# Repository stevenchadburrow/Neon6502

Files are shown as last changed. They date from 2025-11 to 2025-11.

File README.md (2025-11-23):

# Neon6502

<b>Compact 6502 build using 74' logic chips.</b>

The idea with this project is to make a cheap 4" x 4" PCB that can fit most of the functionality of my original <a href="https://github.com/stevenchadburrow/AcolyteComputer">Acolyte Computer</a>.  The purpose is to play games such as Tetris and Space Invaders clones that I will program in 6502 assembly.  I also made a simulator program is to help speed up development time and lessen the amount of Flash ROM burns.<br>

I'm doing this in order to wait for the <a href="https://www.microchip.com/en-us/product/PIC32CZ8110CA80144">PIC32CZ8110CA80144</a> microcontroller to come out in the LQFP-144 package (promised Q4 of 2025!).  Once that is out, I will get back to projects similar to my <a href="https://github.com/stevenchadburrow/AcolyteHandheld">Acolyte Handheld<a>.<br>

<b>Specs:</b><br>
- W65C02 running at 3.14 MHz<br>
- 32 KB of RAM (30 KB of which is Video RAM)<br>
- 32 KB of ROM (4x switchable banks)<br>
- 8x Built-in Buttons<br>
- VGA Output of 320x240 in 4-colors<br>
- Uses only 74' logic chips and the Flash ROM to generate the video signal!<br>
- USB-B to power device<br>
- No VIA, no UART, no keyboard, no audio, no external memory<br>

<b>Memory Map:</b><br>
- $0000 - $07FF = RAM<br>
- $0800 - $7FFF = Video RAM<br>
- $8000 - $FFFF = ROM<br>

<b>History:</b><br>
As this is a revisiting of previous projects and skills, I feel the need to try to catalog my progress up to this point.  Below is a timeline of projects completed with a few details.<br>
- Aug 2021: After the quarantine, I went back to work at the school physically.  I never went upstairs into my office but stayed in my classroom with a Linux computer to occupy my time.  I started researching how to make a water-based calculator, but found electricity to be far better.  I researched about 74' logic chips and eventually reached out to Garth who redirected me to the 6502.org Forum <a href="http://forum.6502.org/">here</a>.
- Oct 2021: This marks the very beginning of the journey, my first 6502 build, called "V1" by Bill (plasmo).  Made on perf-board, each wire hand-soldered.  I had crossed A4 and A11 on the RAM, Bill found this and fixed it for me.  It had only a couple of buttons and a 16x2 LCD.
- Nov 2021: I made a duplicate of V1 on a PCB, which I called "V2".  No bodges were required, though it wasn't very useful.  Far later I would use this as the basis for a project where Elizabeth soldered her own computer together.
- Jan 2022: I made V3 and even a V4, adding features such as PS/2 keyboard and ROM banks.  I tried to add VGA video using 74' logic chips for all sync calculations, but they were all failures.
- Mar 2022: In order to create a VGA video signal, I created my "Half a Pi" board, using a dedicated Flash ROM for video signals.  It was able to output White, Red, Cyan, and Black.  I was able to showcase it at the upcoming Math Appreciation Day 2022 <a href="http://forum.6502.org/viewtopic.php?f=1&t=7092">here</a>.
- Jul 2022: By now I had tried to replicate the "Half a Pi" with more complexity, and yet I continued to have failures.  At some point I had started calling them "Acolyte", though apparently the first versions were not operational.  The main goal was to combine both the sync signals and the program code onto a single Flash ROM.  Some were successes, even if they were complex, found <a href="http://forum.6502.org/viewtopic.php?f=4&t=7154">here</a>.
- Nov 2022: At this point I was still making mistakes and a lot of my PCBs would not work.  A revelation came to be at some point here that I could simply bodge wires to fix problems, which helped a lot.  You can find a lot of the discussion <a href="http://forum.6502.org/viewtopic.php?f=4&t=7407">here</a>.
- Jan 2023: The final culmination of the original Acolyte computers comes together <a href="https://github.com/stevenchadburrow/AcolyteComputer">here</a>.  It was named "Last Acolyte II".  It has so many bodge wires, mostly for experimenting and adding a VIA into the expansion area.  The back of that board looks like spagetti with all of the bodges!  It had Tetris, Space Invaders, BASIC, and a Monitor program.
- Apr 2023: I started designing the "Serial VGA" projects <a href="https://github.com/stevenchadburrow/SerialVGA">here</a>, which could be connected to any random 6502 computer.  After some revisions they started to work, but were not very efficient, being too slow.  I also played around with the Arduino, and created a CPLD-based shield <a href="https://github.com/stevenchadburrow/ArduinoShield">here</a>.
- Sep 2023: By now I had been working with CPLDs and learning Verilog, and created what I called "New Acolyte" <a href="https://github.com/stevenchadburrow/NewAcolyte">here</a>, which ran twice as fast and relied on the CPLD for video generation with 16 colors.  I connected a Sega Genesis controller to it, and was able to create many fun games for it, including Tetris, Space Invaders, Missile Command, Rogue, and Galaga clones.
- Dec 2023: After other failed revisions, it was time to go bigger and better, and so I developed my 'masterpiece', the "Acolyte816" <a href="https://github.com/stevenchadburrow/Acolyte816">here</a>.  It used a 65816 processor, CPLD for video generation, and a PIC16 micrcontroller for bootloading.  It did work, but was so complex that it was very hard to develop for.  Because of that, not much time was spent on it.
- Feb 2024: Enticed by the PIC16 which Garth had introduced to me, I started work on a PIC18 microcontroller based computer called "Acolyte Hand PIC'd", found <a href="https://github.com/stevenchadburrow/AcolyteHandPICd">here</a>.  It was a separation from the 6502 based computers, finally breaking away and being able to use C programming.  It still using a CPLD and external RAM for video generation.  I was able to get Tetris to run on it.  I would try another PIC18 project later that failed to work because I made it too complex.
- May 2024: I created a PIC24 microcontroller based computer called "Acolyte Hand PIC'd 24" <a href="https://github.com/stevenchadburrow/AcolyteHandPICd24">here</a>.  I was final able to break away from using the CPLD and external RAM for video generation, still yielding 16 colors.  Small additions to test USB host and device capabilities were added.  Then during Summer 2024 I created a two-player Pokemon clone for this computer, pushing the PIC24 to the very limit.
- Oct 2024: I upgraded to the PIC32 microcontroller, creating a computer called the "Acolyte Hand PIC'd 32" with absolutely stunning results <a href="https://github.com/stevenchadburrow/AcolyteHandPICd32">here</a>.  I started running it at 200 MHz, displaying 256 colors.  I bodged in better audio capabilities using an R2R DAC and was able to play video/audio streams.
- Dec 2024: After trying to port an NES emulator to the PIC32 board, and failing to reach the needed speed, I found the Peanut-GB Emulator by Mahyar <a href="https://github.com/deltabeard/Peanut-GB">here</a>.  It ran Gameboy games at full speed.  I quickly made a second revision of the PIC32 board with 64K color capability and 2x 8-bit R2R DACs.
- Jan 2025: Wanting to create a handheld device of some kind, I created "Mon Catcher" using a PIC24 and a small LCD.  It was going to be a dedicated device that would act similar to Pokemon GO, using sensors to detect movement.  It worked, but the sensors were not great and I got bored of it quickly. ( No links provided. )
- Feb 2025: I started work on what would later be called "PICnes" <a href="https://github.com/stevenchadburrow/PICnes">here</a>.  By April 2025 it would have all of the popular NES mappers including MMC3.
- Jun 2025: My dream forever has been to have a 'switchable' platform, and so I finally created the "Acolyte Handheld" <a href="https://github.com/stevenchadburrow/AcolyteHandheld">here</a>.  Capable of switching between VGA and LCD outputs, and being overclocked to 300 MHz, it was able to run nearly all NES games at full speed.  Along with Peanut-GB, I added TotalSMS <a href="https://github.com/ITotalJustice/TotalSMS">here</a>, for Sega Master System and Game Gear games.  Over Summer 2025 it was finalized.
- Aug 2025: In an attempt to shrink the Acolyte Handheld down, I created what I called the "Second Handheld", which would be my 'masterpiece' with the PIC32.  Unfortunately, I was not able to overclock it to 300 MHz, and many of the complex features such as external Flash ROM I had added were not working.  It ultimately ended a failure, however beautiful it was.  It seems that my 'masterpieces' always end in failure? ( No links provided. )
- Sep 2025: Seeking to make the next project better than the PIC32, I started the "RPi02W-Emulators" project <a href="https://github.com/stevenchadburrow/RPi02W-Emulators">here</a>.  Using a Raspberry Pi Zero 2W, I was able to make it 'switchable' between and LCD screen and HDMI output.  Programming in Linux was very enjoyable, though ultimately this project also proved to be a failure.  It ran NES and GB games easily enough, but Gameboy Advance games were still too slow.  The screen would have a tearing effect and the audio was scratchy, mainly because I decided to user /dev/fb0 and /dev/dsp for all of my video and audio needs.  The Linux overhead just didn't make it work as well as I had wanted.  It does run Freedoom, but only on HDMI.
- Nov 2025: And here we are, creating "Neon6502".  There is my journey.

<b>Links:</b><br>
<a href="https://www.youtube.com/shorts/nDpJQxdZJzY">Youtube Short playing Tetra</a><br>

<b>Pictures:</b><br>
Pictures of the PCB design, some footprints too small. Gerber files included.<br>
<br>
Testing out the image converter, assembly code, and simulator.<br>
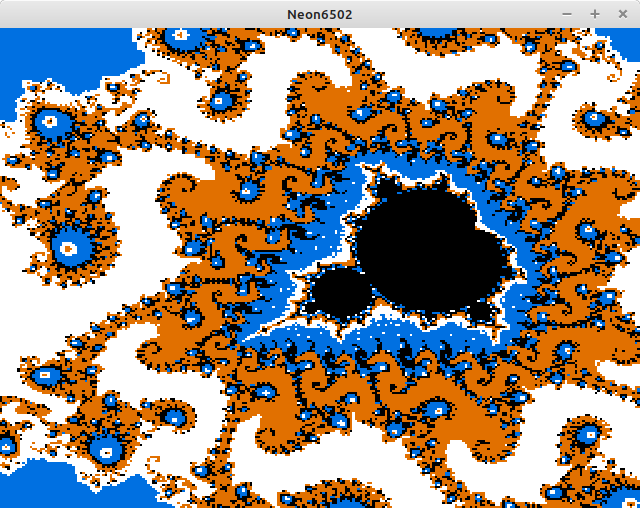
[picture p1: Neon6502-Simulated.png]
<br>
Soldered PCB with all components.  Only one bodge wire!<br>
<br>
Actual program on VGA monitor.<br>
<br>
Tetra is always the first game.<br>
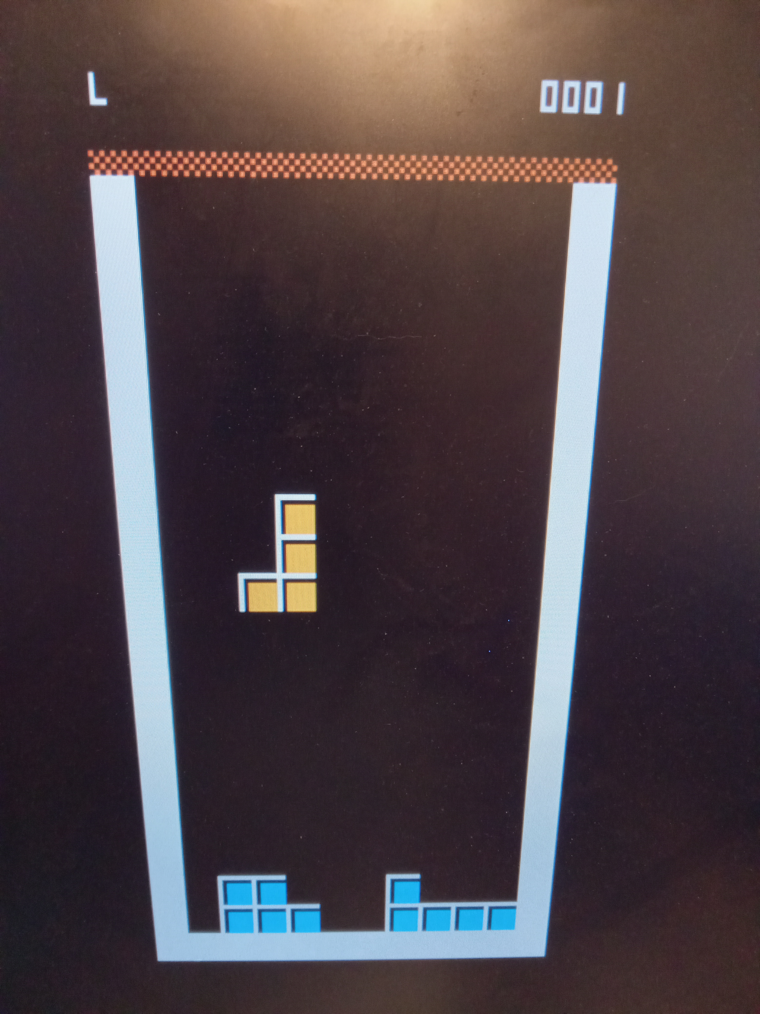
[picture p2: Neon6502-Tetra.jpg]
<br>
Enclosure uses same color palette.<br>
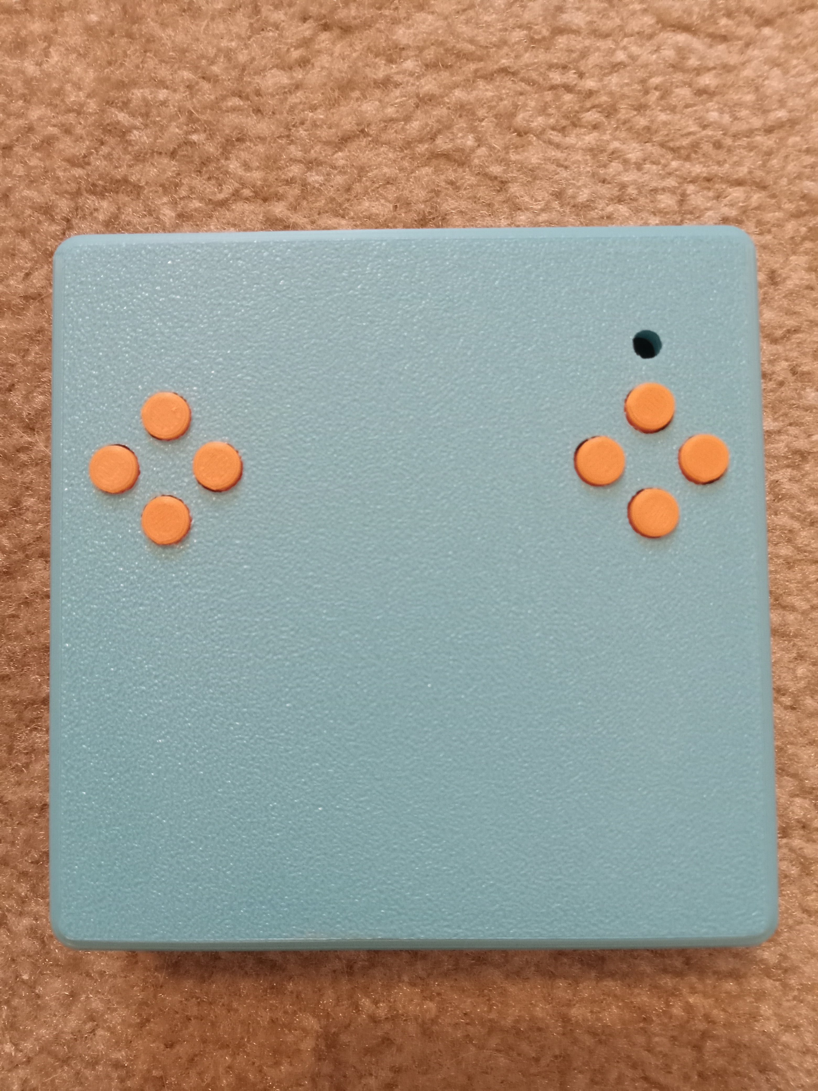
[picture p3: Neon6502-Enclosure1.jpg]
<br>
Ports fit flush with enclosure.<br>
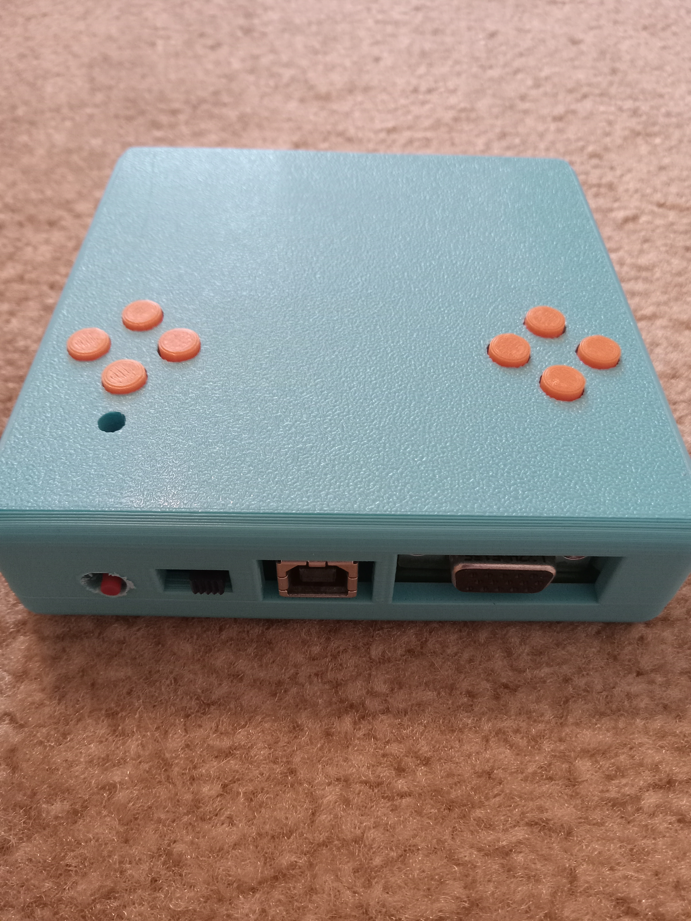
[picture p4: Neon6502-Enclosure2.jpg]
<br>

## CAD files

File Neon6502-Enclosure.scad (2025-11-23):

// Neon6502

module radiusedblock(xlen,ylen,zlen,radius) {
	hull() {
		translate([radius,radius,radius]) sphere(r=radius);
		translate([xlen + radius , radius , radius]) sphere(r=radius);
		translate([radius , ylen + radius , radius]) sphere(r=radius);    
		translate([xlen + radius , ylen + radius , radius]) sphere(r=radius);
		translate([radius , radius , zlen + radius]) sphere(r=radius);
		translate([xlen + radius , radius , zlen + radius]) sphere(r=radius);
		translate([radius,ylen + radius,zlen + radius]) sphere(r=radius);
		translate([xlen + radius,ylen + radius,zlen + radius]) sphere(r=radius);
	}
}

$fn = 20; // higher detail to curves


scale([1,-1,1])
{
	difference()
	{
		// outside
		translate([-5,-5,-5])
		{
			radiusedblock(100,100,20,5);
		}
		
		// inside
		translate([-1,-1,0])
		{
			cube([102,102,20]);
		}
			
		// vga
		translate([9,-10,5])
		{
			cube([33,20,14]);
		}
			
		// usb
		translate([45,-10,5])
		{
			cube([17.5,20,12]);
		}
		
		// switch
		translate([67,-10,7])
		{
			cube([11,20,7]);
		}
		
		// reset
		translate([85.75,-10,4])
		{
			rotate([-90,0,0])
			{
				cylinder(20,2.5,2.5);
			}
		}
		
		// led
		translate([86.25,15.0,10])
		{
			cylinder(20,2.5,2.5);
		}
		
		// buttons
		translate([14.25,24.75,10])
		{
			cylinder(20,4,4);
		}
		translate([14.25,40.25,10])
		{
			cylinder(20,4,4);
		}
		translate([6.5,32.5,10])
		{
			cylinder(20,4,4);
		}
		translate([22.0,32.5,10])
		{
			cylinder(20,4,4);
		}
		
		translate([86.25,24.75,10])
		{
			cylinder(20,4,4);
		}
		translate([86.25,40.25,10])
		{
			cylinder(20,4,4);
		}
		translate([78.5,32.5,10])
		{
			cylinder(20,4,4);
		}
		translate([94.0,32.5,10])
		{
			cylinder(20,4,4);
		}
		
		// screw holes
		translate([4.75,4.75,5])
		{
			rotate([180,0,0])
			{
				cylinder(20,2.5,2.5);
			}
		}
		translate([95.25,4.75,5])
		{
			rotate([180,0,0])
			{
				cylinder(20,2.5,2.5);
			}
		}
		translate([4.75,95.25,5])
		{
			rotate([180,0,0])
			{
				cylinder(20,2.5,2.5);
			}
		}
		translate([95.25,95.25,5])
		{
			rotate([180,0,0])
			{
				cylinder(20,2.5,2.5);
			}
		}
		
		// comment out for top only
		translate([-10,-10,-10])
		{
			//cube([120,120,10+5]);
		}
		
		// comment out for bottom only
		translate([-10,-10,5])
		{
			//cube([120,120,30]);
		}
	}
	
	difference()
	{
		union()
		{
			// screw supports
			translate([4.75,4.75,0])
			{
				difference()
				{
					cylinder(20,4.5,4.5);
					cylinder(20,1.0,1.0);
				}
			}
			translate([95.25,4.75,0])
			{
				difference()
				{
					cylinder(20,4.5,4.5);
					cylinder(20,1.0,1.0);
				}
			}
			translate([4.75,95.25,0])
			{
				difference()
				{
					cylinder(20,4.5,4.5);
					cylinder(20,1.0,1.0);
				}
			}
			translate([95.25,95.25,0])
			{
				difference()
				{
					cylinder(20,4.5,4.5);
					cylinder(20,1.0,1.0);
				}
			}
			
			// support supports
			translate([1,1,0])
			{
				cylinder(20,3,3);
			}
			translate([99,1,0])
			{
				cylinder(20,3,3);
			}
			translate([1,99,0])
			{
				cylinder(20,3,3);
			}
			translate([99,99,0])
			{
				cylinder(20,3,3);
			}
			
			// button supports
			translate([14.25,24.75,15])
			{
				difference()
				{
					cylinder(5,6,6);
					cylinder(5,4,4);
				}
			}
			translate([14.25,40.25,15])
			{
				difference()
				{
					cylinder(5,6,6);
					cylinder(5,4,4);
				}
			}
			translate([6.5,32.5,15])
			{
				difference()
				{
					cylinder(5,6,6);
					cylinder(5,4,4);
				}
			}
			translate([22.0,32.5,15])
			{
				difference()
				{
					cylinder(5,6,6);
					cylinder(5,4,4);
				}
			}
		
			translate([86.25,24.75,15])
			{
				difference()
				{
					cylinder(5,6,6);
					cylinder(5,4,4);
				}
			}
			translate([86.25,40.25,15])
			{
				difference()
				{
					cylinder(5,6,6);
					cylinder(5,4,4);
				}
			}
			translate([78.5,32.5,15])
			{
				difference()
				{
					cylinder(5,6,6);
					cylinder(5,4,4);
				}
			}
			translate([94.0,32.5,15])
			{
				difference()
				{
					cylinder(5,6,6);
					cylinder(5,4,4);
				}
			}
		}
		
		// pcb
		translate([-10,-10,5-1.6])
		{
			cube([120,120,1.6]);
		}
		
		// comment out for top only
		translate([-10,-10,-10])
		{
			//cube([120,120,10+5]);
		}
		
		// comment out for bottom only
		translate([-10,-10,5])
		{
			//cube([120,120,30]);
		}
	}
}

module button()
{
	difference()
	{
		union()
		{
			cylinder(15, 3.5, 3.5);
			cylinder(2, 5, 5);
			intersection()
			{
				sphere(17);
				cylinder(100, 3.5, 3.5);
			}
		}
		translate([-1.5, -1.5, 0])
		{
			cube([3.0, 3.0, 3.0]);
		}
	}
}


scale([1,-1,1])
{
	translate([14.25,24.75,10])
	{
		button();
	}
	translate([14.25,40.25,10])
	{
		button();
	}
	translate([6.5,32.5,10])
	{
		button();
	}
	translate([22.0,32.5,10])
	{
		button();
	}
	
	translate([86.25,24.75,10])
	{
		button();
	}
	translate([86.25,40.25,10])
	{
		button();
	}
	translate([78.5,32.5,10])
	{
		button();
	}
	translate([94.0,32.5,10])
	{
		button();
	}
}

//button();

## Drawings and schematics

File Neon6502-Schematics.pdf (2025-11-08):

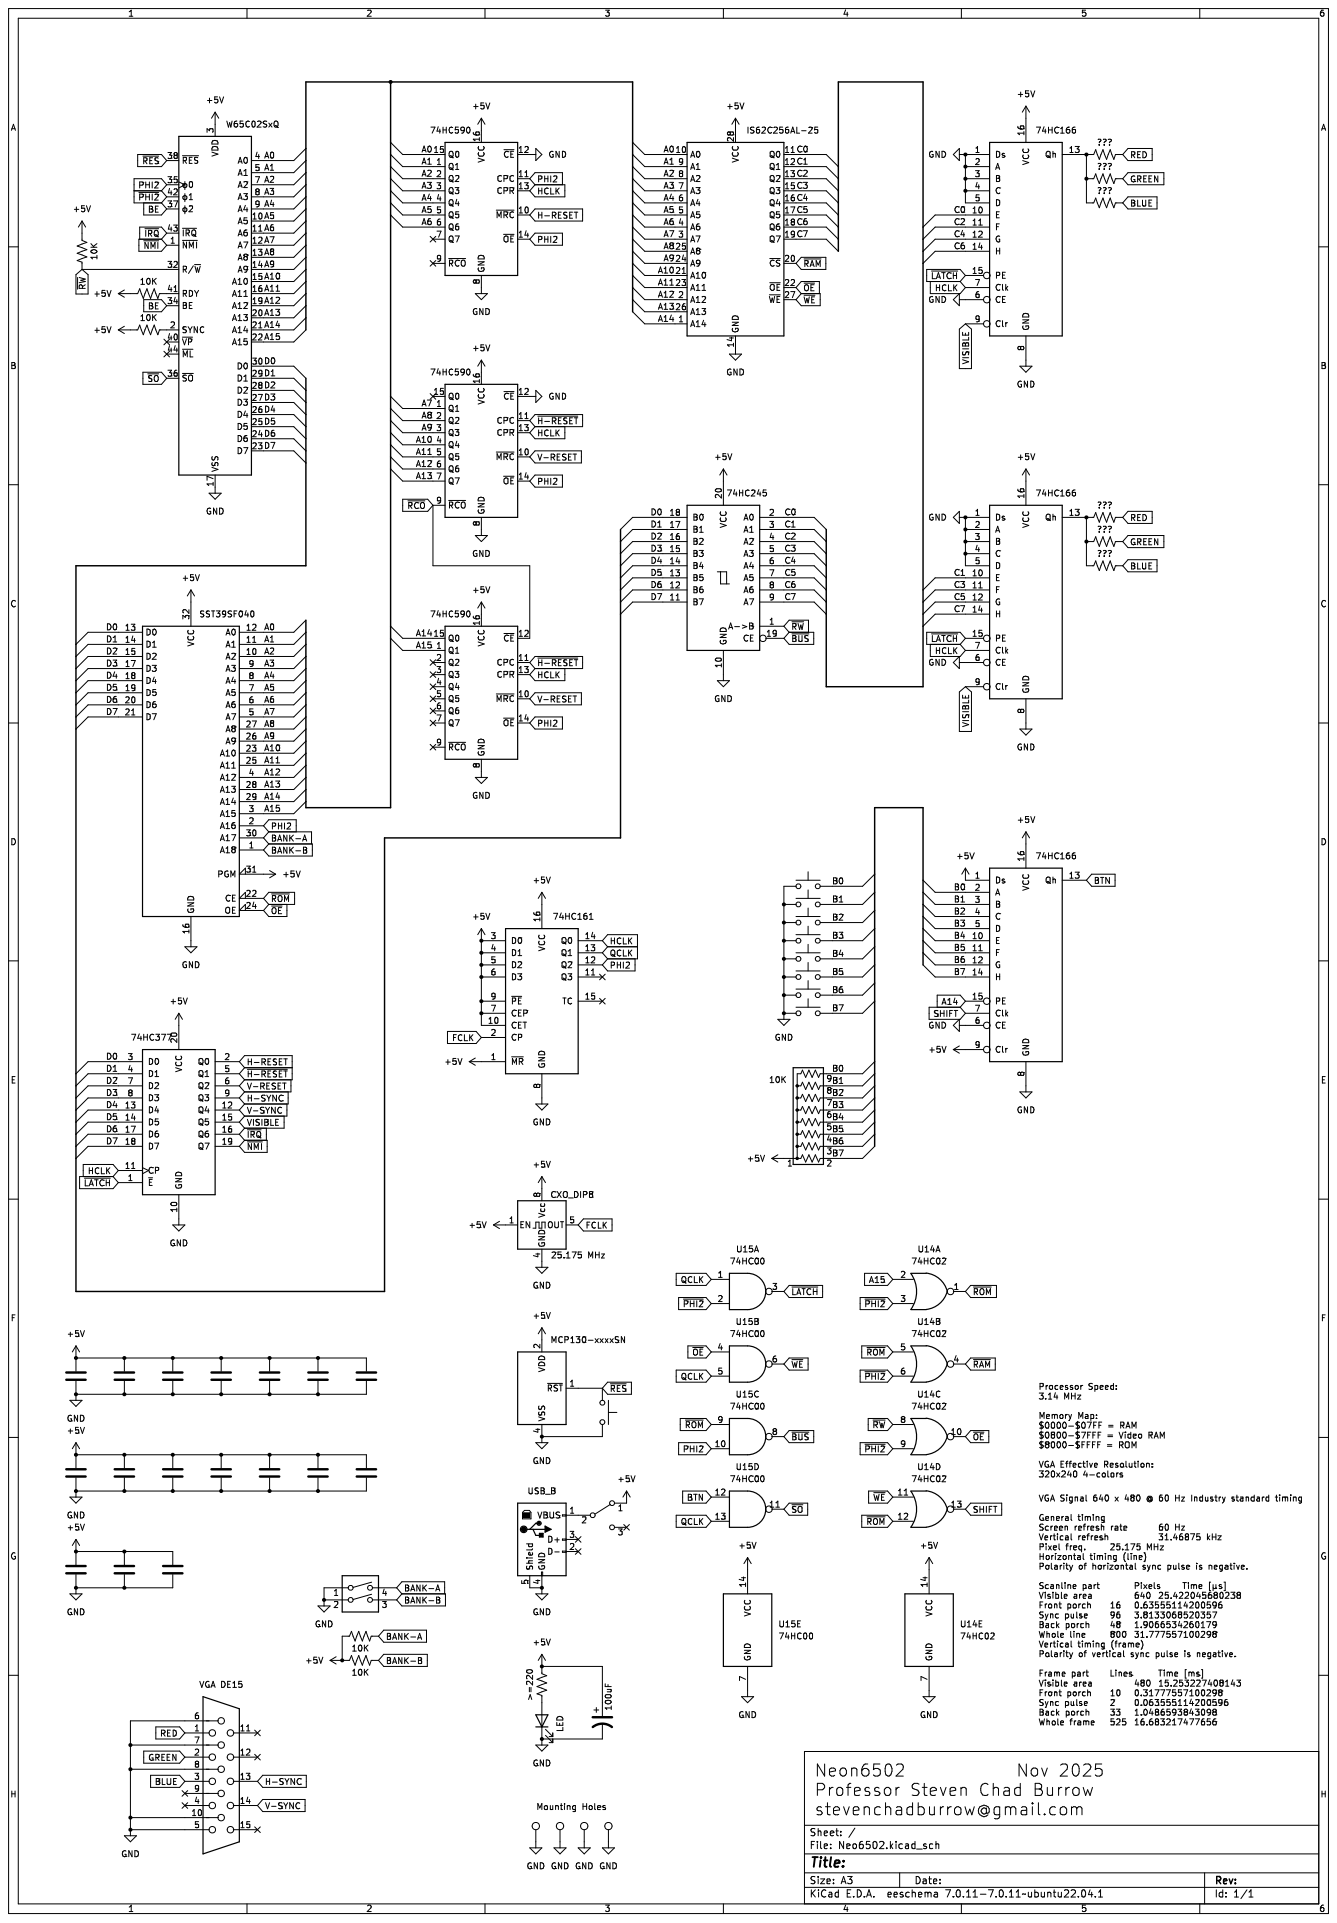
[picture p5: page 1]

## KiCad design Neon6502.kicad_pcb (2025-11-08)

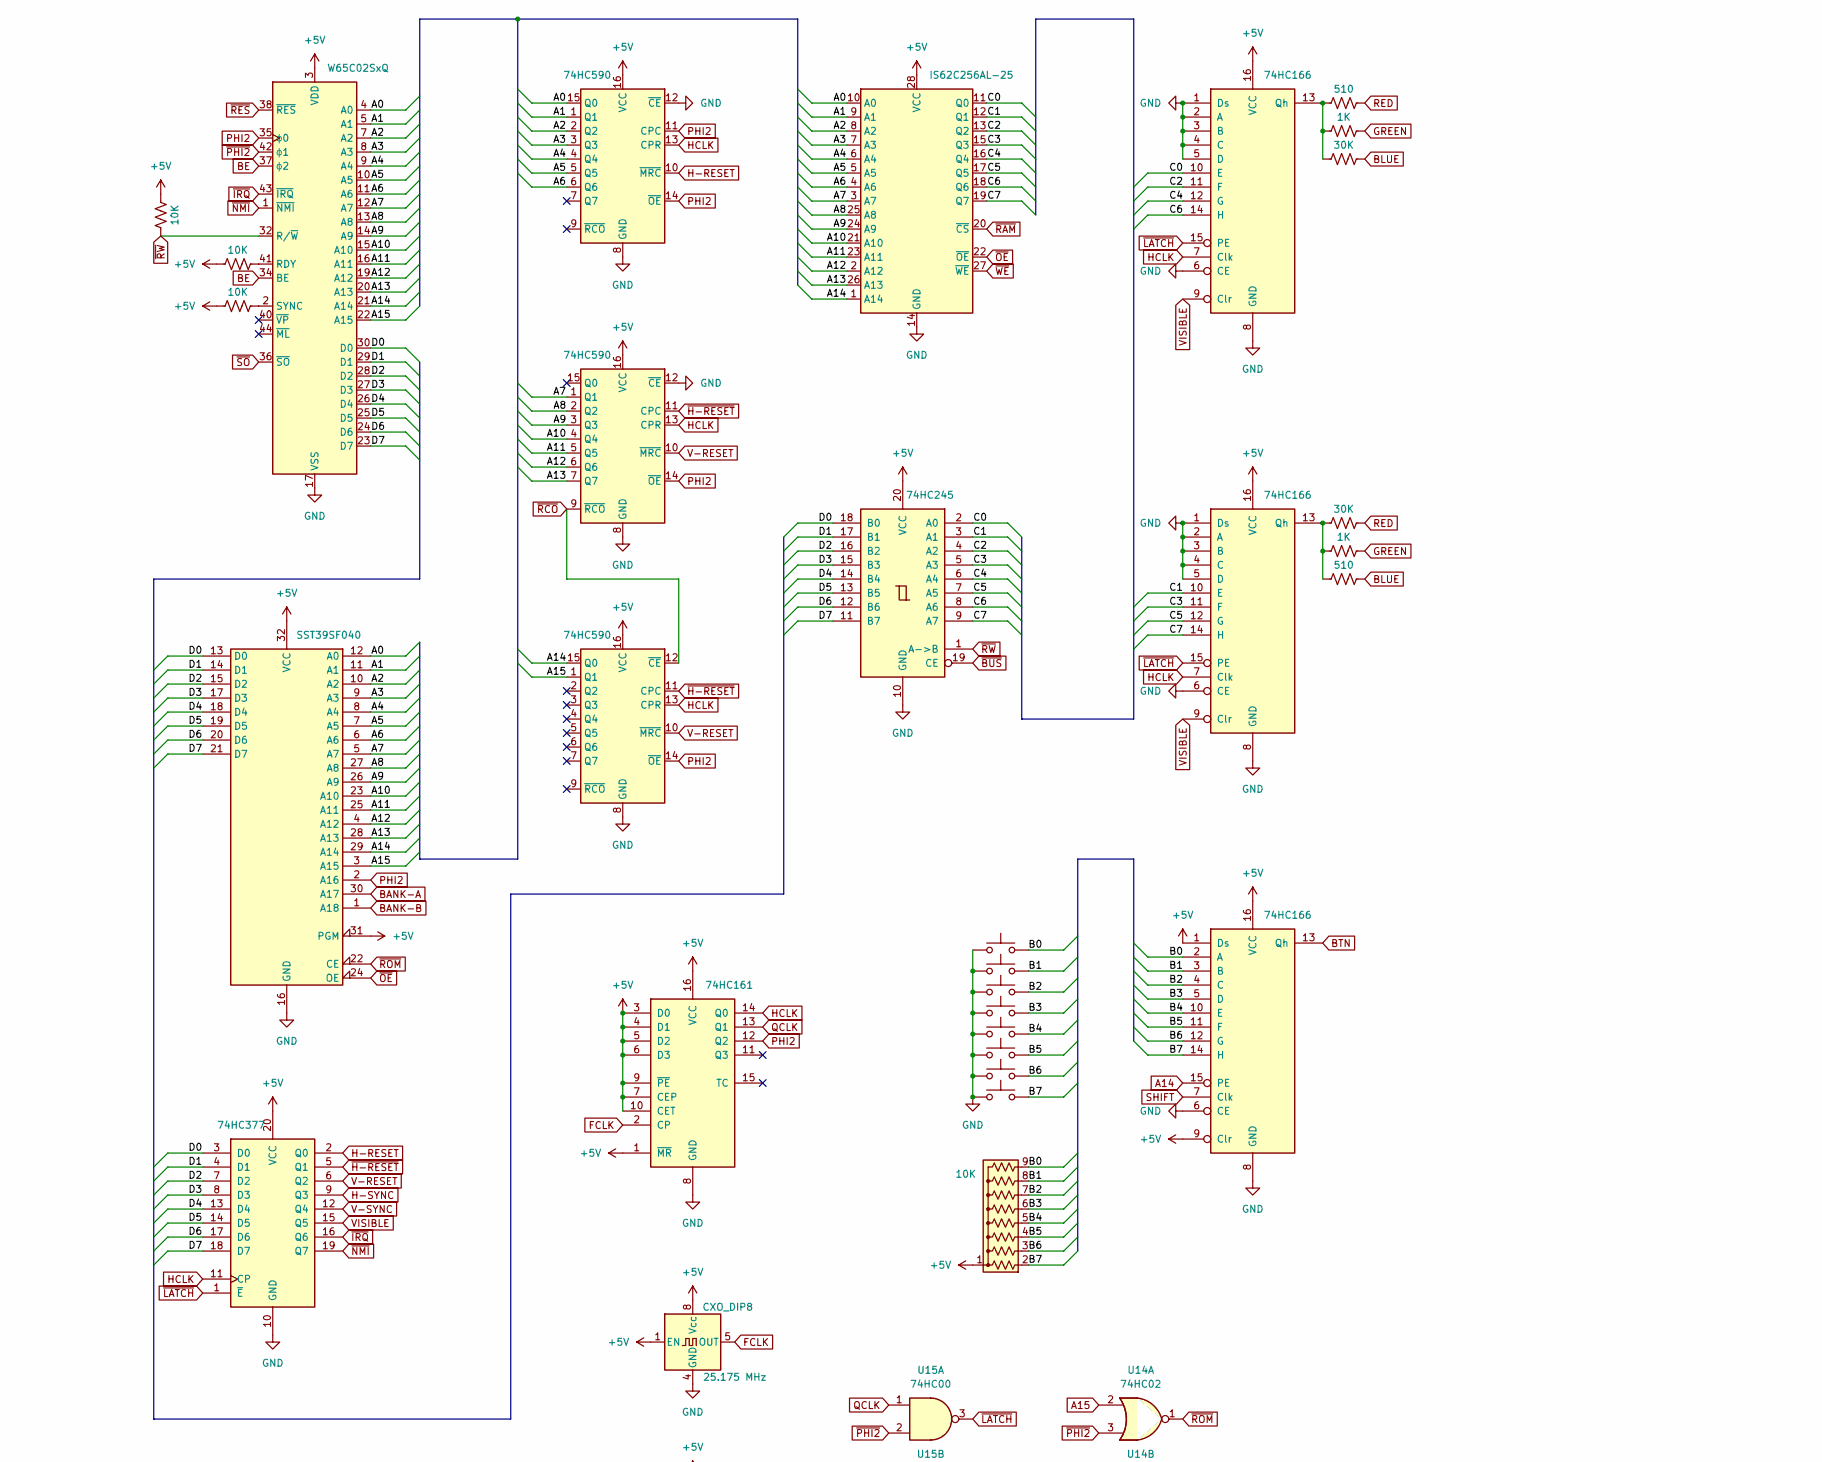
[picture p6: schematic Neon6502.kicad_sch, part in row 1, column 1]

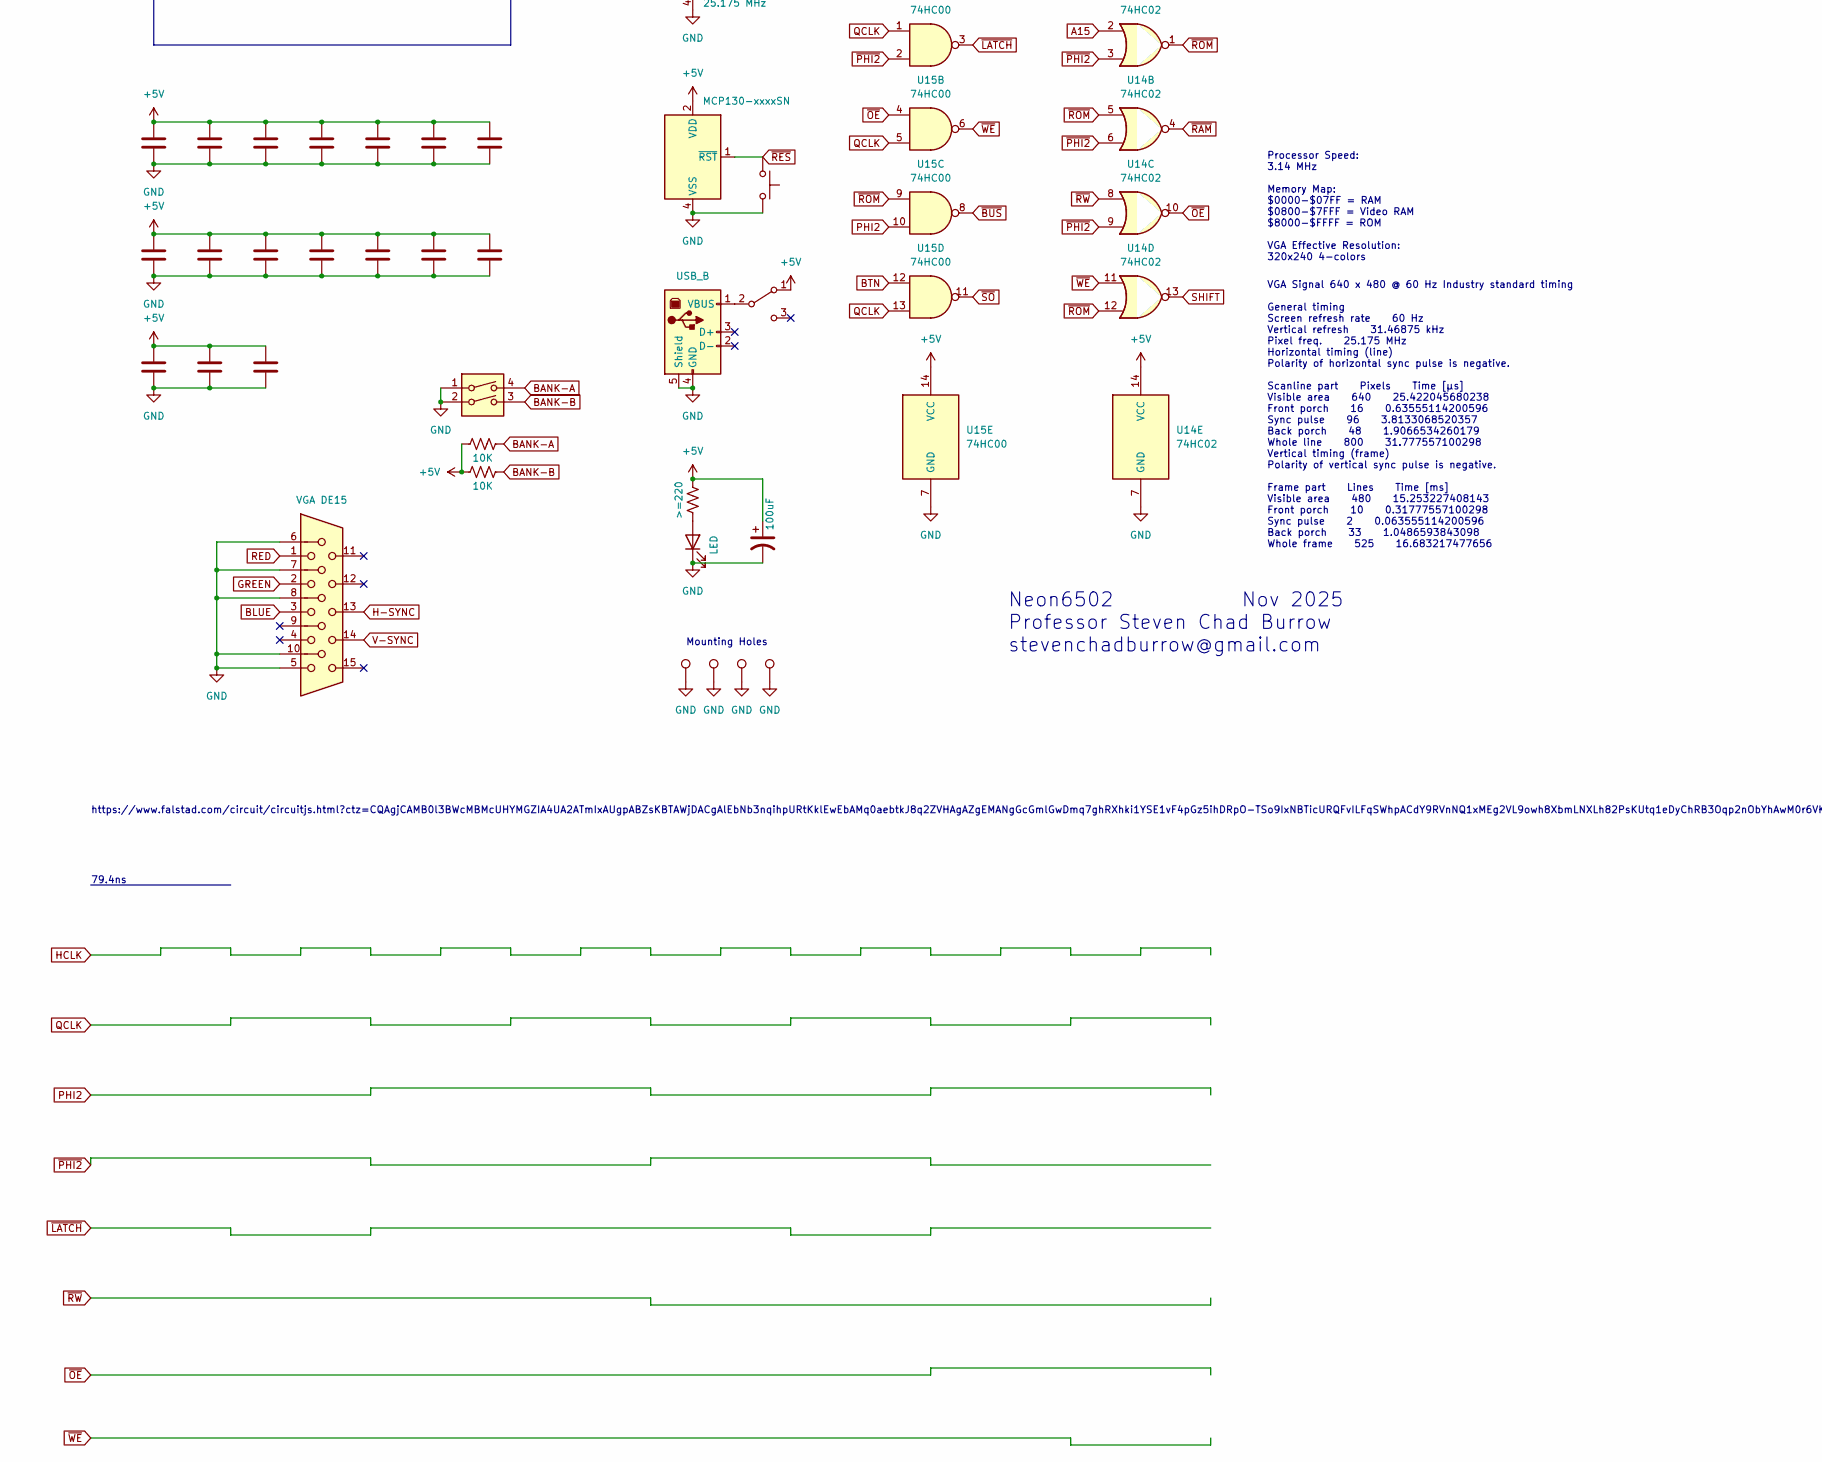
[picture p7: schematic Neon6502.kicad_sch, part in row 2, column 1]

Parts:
C1: C_Polarized_US; CP_Radial_D6.3mm_P2.50mm
C2, C3, C4, C5, C6, C7, C8, C9, C10, C11, C12, C13, C14, C15, C16, C17, C18: C; C_1206_3216Metric_Pad1.33x1.80mm_HandSolder
D1: LED; CustomLED
J1: DE15_Receptacle_HighDensity; DSUB-15-HD_Female_Horizontal_P2.29x2.54mm_VGA
J2: USB_B; USB_B_Lumberg_2411_02_Horizontal
R1, R2, R3, R4, R5, R6, R7, R8, R9, R10, R11, R12: R_US; R_1206_3216Metric_Pad1.30x1.75mm_HandSolder
RN1: R_Network08_US; R_Array_SIP9
SW1, SW2, SW3, SW4, SW5, SW6, SW7, SW8: SW_Push; SW_PUSH_6mm_H5mm
SW9: SW_SPDT; SW_E-Switch_EG1224_SPDT_Angled
SW10: SW_Push; SW_Tactile_SPST_Angled_PTS645Vx83-2LFS
SW11: SW_DIP_x02; SW_DIP_SPSTx02_Slide_9.78x7.26mm_W7.62mm_P2.54mm
TP1, TP2, TP3, TP4: TestPoint; ScrewHole-4-40
U1: IS62C256AL-25; SOP-28_8.4x18.5mm_P1.27mm
U2, U3, U4: 74HC590; SO-16_3.9x9.9mm_P1.27mm
U5, U6, U12: 74HC166; SO-16_3.9x9.9mm_P1.27mm
U7: 74HC161; SO-16_3.9x9.9mm_P1.27mm
U8: MCP130-xxxxSN; SOIC-8_3.9x4.9mm_P1.27mm
U9: SST39SF040; DIP-32_W15.24mm_Socket
U10: 74HC377; SO-20_5.3x12.6mm_P1.27mm
U11: 74HC245; SO-20_5.3x12.6mm_P1.27mm
U13: W65C02SxQ; MQFP-44_10x10mm_P0.8mm
U14: 74HC02; SO-14_3.9x8.65mm_P1.27mm
U15: 74HC00; SO-14_3.9x8.65mm_P1.27mm
X2: CXO_DIP8; Oscillator_DIP-8

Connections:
+5V: C1.1, C2.1, C3.1, C4.1, C5.1, C6.1, C7.1, C8.1, C9.1, C10.1, C11.1, C12.1, C13.1, C14.1, C15.1, C16.1, C17.1, C18.1, R1.1, R2.1, R9.1, R10.1, R11.2, R12.1, RN1.1 (common), SW9.1 (A), U1.28 (VCC), U2.16 (VCC), U3.16 (VCC), U4.16 (VCC), U5.16 (VCC), U6.16 (VCC), U7.1 (~MR), U7.3 (D0), U7.4 (D1), U7.5 (D2), U7.6 (D3), U7.7 (CEP), U7.9 (~PE), U7.10 (CET), U7.16 (VCC), U8.2 (VDD), U9.31 (PGM), U9.32 (VCC), U10.20 (VCC), U11.20 (VCC), U12.1 (Ds), U12.9 (Clr), U12.16 (VCC), U13.3 (VDD), U13.31 (VDD), U14.14 (VCC), U15.14 (VCC), X2.1 (EN), X2.8 (Vcc)
/A0: U1.10 (A0), U2.15 (Q0), U9.12 (A0), U13.4 (A0)
/A1: U1.9 (A1), U2.1 (Q1), U9.11 (A1), U13.5 (A1)
/A2: U1.8 (A2), U2.2 (Q2), U9.10 (A2), U13.7 (A2)
/A3: U1.7 (A3), U2.3 (Q3), U9.9 (A3), U13.8 (A3)
/A4: U1.6 (A4), U2.4 (Q4), U9.8 (A4), U13.9 (A4)
/A5: U1.5 (A5), U2.5 (Q5), U9.7 (A5), U13.10 (A5)
/A6: U1.4 (A6), U2.6 (Q6), U9.6 (A6), U13.11 (A6)
/A7: U1.3 (A7), U3.1 (Q1), U9.5 (A7), U13.12 (A7)
/A8: U1.25 (A8), U3.2 (Q2), U9.27 (A8), U13.13 (A8)
/A9: U1.24 (A9), U3.3 (Q3), U9.26 (A9), U13.14 (A9)
/A10: U1.21 (A10), U3.4 (Q4), U9.23 (A10), U13.15 (A10)
/A11: U1.23 (A11), U3.5 (Q5), U9.25 (A11), U13.16 (A11)
/A12: U1.2 (A12), U3.6 (Q6), U9.4 (A12), U13.19 (A12)
/A13: U1.26 (A13), U3.7 (Q7), U9.28 (A13), U13.20 (A13)
/B0: RN1.9 (R8), SW1.2, U12.2 (A)
/B1: RN1.8 (R7), SW2.2, U12.3 (B)
/B2: RN1.7 (R6), SW3.2, U12.4 (C)
/B3: RN1.6 (R5), SW4.2, U12.5 (D)
/B4: RN1.5 (R4), SW5.2, U12.10 (E)
/B5: RN1.4 (R3), SW6.2, U12.11 (F)
/B6: RN1.3 (R2), SW7.2, U12.12 (G)
/B7: RN1.2 (R1), SW8.2, U12.14 (H)
/C0: U1.11 (Q0), U5.10 (E), U11.2 (A0)
/C1: U1.12 (Q1), U6.10 (E), U11.3 (A1)
/C2: U1.13 (Q2), U5.11 (F), U11.4 (A2)
/C3: U1.15 (Q3), U6.11 (F), U11.5 (A3)
/C4: U1.16 (Q4), U5.12 (G), U11.6 (A4)
/C5: U1.17 (Q5), U6.12 (G), U11.7 (A5)
/C6: U1.18 (Q6), U5.14 (H), U11.8 (A6)
/C7: U1.19 (Q7), U6.14 (H), U11.9 (A7)
/D0: U9.13 (D0), U10.3 (D0), U11.18 (B0), U13.30 (D0)
/D1: U9.14 (D1), U10.4 (D1), U11.17 (B1), U13.29 (D1)
/D2: U9.15 (D2), U10.7 (D2), U11.16 (B2), U13.28 (D2)
/D3: U9.17 (D3), U10.8 (D3), U11.15 (B3), U13.27 (D3)
/D4: U9.18 (D4), U10.13 (D4), U11.14 (B4), U13.26 (D4)
/D5: U9.19 (D5), U10.14 (D5), U11.13 (B5), U13.25 (D5)
/D6: U9.20 (D6), U10.17 (D6), U11.12 (B6), U13.24 (D6)
/D7: U9.21 (D7), U10.18 (D7), U11.11 (B7), U13.23 (D7)
A14: U1.1 (A14), U4.15 (Q0), U9.29 (A14), U12.15 (PE), U13.21 (A14)
A15: U4.1 (Q1), U9.3 (A15), U13.22 (A15), U14.2
BANK-A: R10.2, SW11.4, U9.30 (A17)
BANK-B: R12.2, SW11.3, U9.1 (A18)
BE: U13.34 (BE), U13.37 (ϕ2)
BLUE: J1.3, R5.2, R8.2
BTN: U12.13 (Qh), U15.12
FCLK: U7.2 (CP), X2.5 (OUT)
GND: C1.2, C2.2, C3.2, C4.2, C5.2, C6.2, C7.2, C8.2, C9.2, C10.2, C11.2, C12.2, C13.2, C14.2, C15.2, C16.2, C17.2, C18.2, D1.1 (K), J1.5, J1.6, J1.7, J1.8, J1.10, J2.4 (GND), J2.5 (Shield), SW1.1, SW2.1, SW3.1, SW4.1, SW5.1, SW6.1, SW7.1, SW8.1, SW10.2, SW11.1, SW11.2, TP1.1, TP2.1, TP3.1, TP4.1, U1.14 (GND), U2.8 (GND), U2.12 (~CE), U3.8 (GND), U3.12 (~CE), U4.8 (GND), U5.1 (Ds), U5.2 (A), U5.3 (B), U5.4 (C), U5.5 (D), U5.6 (CE), U5.8 (GND), U6.1 (Ds), U6.2 (A), U6.3 (B), U6.4 (C), U6.5 (D), U6.6 (CE), U6.8 (GND), U7.8 (GND), U8.4 (VSS), U9.16 (GND), U10.10 (GND), U11.10 (GND), U12.6 (CE), U12.8 (GND), U13.17 (VSS), U13.18 (VSS), U13.39 (VSS), U14.7 (GND), U15.7 (GND), X2.4 (GND)
GREEN: J1.2, R4.2, R7.2
H-RESET: U2.10 (~MRC), U10.2 (Q0)
H-SYNC: J1.13, U10.9 (Q3)
HCLK: U2.13 (CPR), U3.13 (CPR), U4.13 (CPR), U5.7 (Clk), U6.7 (Clk), U7.14 (Q0), U10.11 (CP)
unnamed: D1.2 (A), R11.1
unnamed: J2.1 (VBUS), SW9.2 (B)
unnamed: R3.1, R4.1, R5.1, U5.13 (Qh)
unnamed: R6.1, R7.1, R8.1, U6.13 (Qh)
unnamed: R2.2, U13.41 (RDY)
unnamed: R1.2, U13.2 (SYNC)
PHI2: U2.11 (CPC), U2.14 (~OE), U3.14 (~OE), U4.14 (~OE), U7.12 (Q2), U9.2 (A16), U13.35 (ϕ0), U15.10
QCLK: U7.13 (Q1), U15.1, U15.5, U15.13
RED: J1.1, R3.2, R6.2
SHIFT: U12.7 (Clk), U14.13
V-RESET: U3.10 (~MRC), U4.10 (~MRC), U10.6 (Q2)
V-SYNC: J1.14, U10.12 (Q4)
VISIBLE: U5.9 (Clr), U6.9 (Clr), U10.15 (Q5)
~BUS: U11.19 (CE), U15.8
~H-RESET: U3.11 (CPC), U4.11 (CPC), U10.5 (Q1)
~IRQ: U10.16 (Q6), U13.43 (~IRQ)
~LATCH: U5.15 (PE), U6.15 (PE), U10.1 (~E), U15.3
~NMI: U10.19 (Q7), U13.1 (~NMI)
~OE: U1.22 (~OE), U9.24 (OE), U14.10, U15.4
~PHI2: U13.42 (ϕ1), U14.3, U14.6, U14.9, U15.2
~RAM: U1.20 (~CS), U14.4
~RCO: U3.9 (~RCO), U4.12 (~CE)
~RES: SW10.1, U8.1 (~RST), U13.38 (~RES)
~ROM: U9.22 (CE), U14.1, U14.5, U14.12, U15.9
~RW: R9.2, U11.1 (A->B), U13.32 (R/~W), U14.8
~SO: U13.36 (~SO), U15.11
~WE: U1.27 (~WE), U14.11, U15.6

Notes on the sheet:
79.4ns
Mounting Holes
VGA Signal 640 x 480 @ 60 Hz Industry standard timing General timing Screen refresh rate 60 Hz Vertical refresh 31.46875 kHz Pixel freq. 25.175 MHz Horizontal timing (line) Polarity of horizontal sync pulse is negative. Scanline part Pixels Time [µs] Visible area 640 25.422045680238 Front porch 16 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
Neon6502 Nov 2025 Professor Steven Chad Burrow stevenchadburrow@gmail.com
Processor Speed: 3.14 MHz Memory Map: $0000-$07FF = RAM $0800-$7FFF = Video RAM $8000-$FFFF = ROM VGA Effective Resolution: 320x240 4-colors
https://www.falstad.com/circuit/circuitjs.html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…

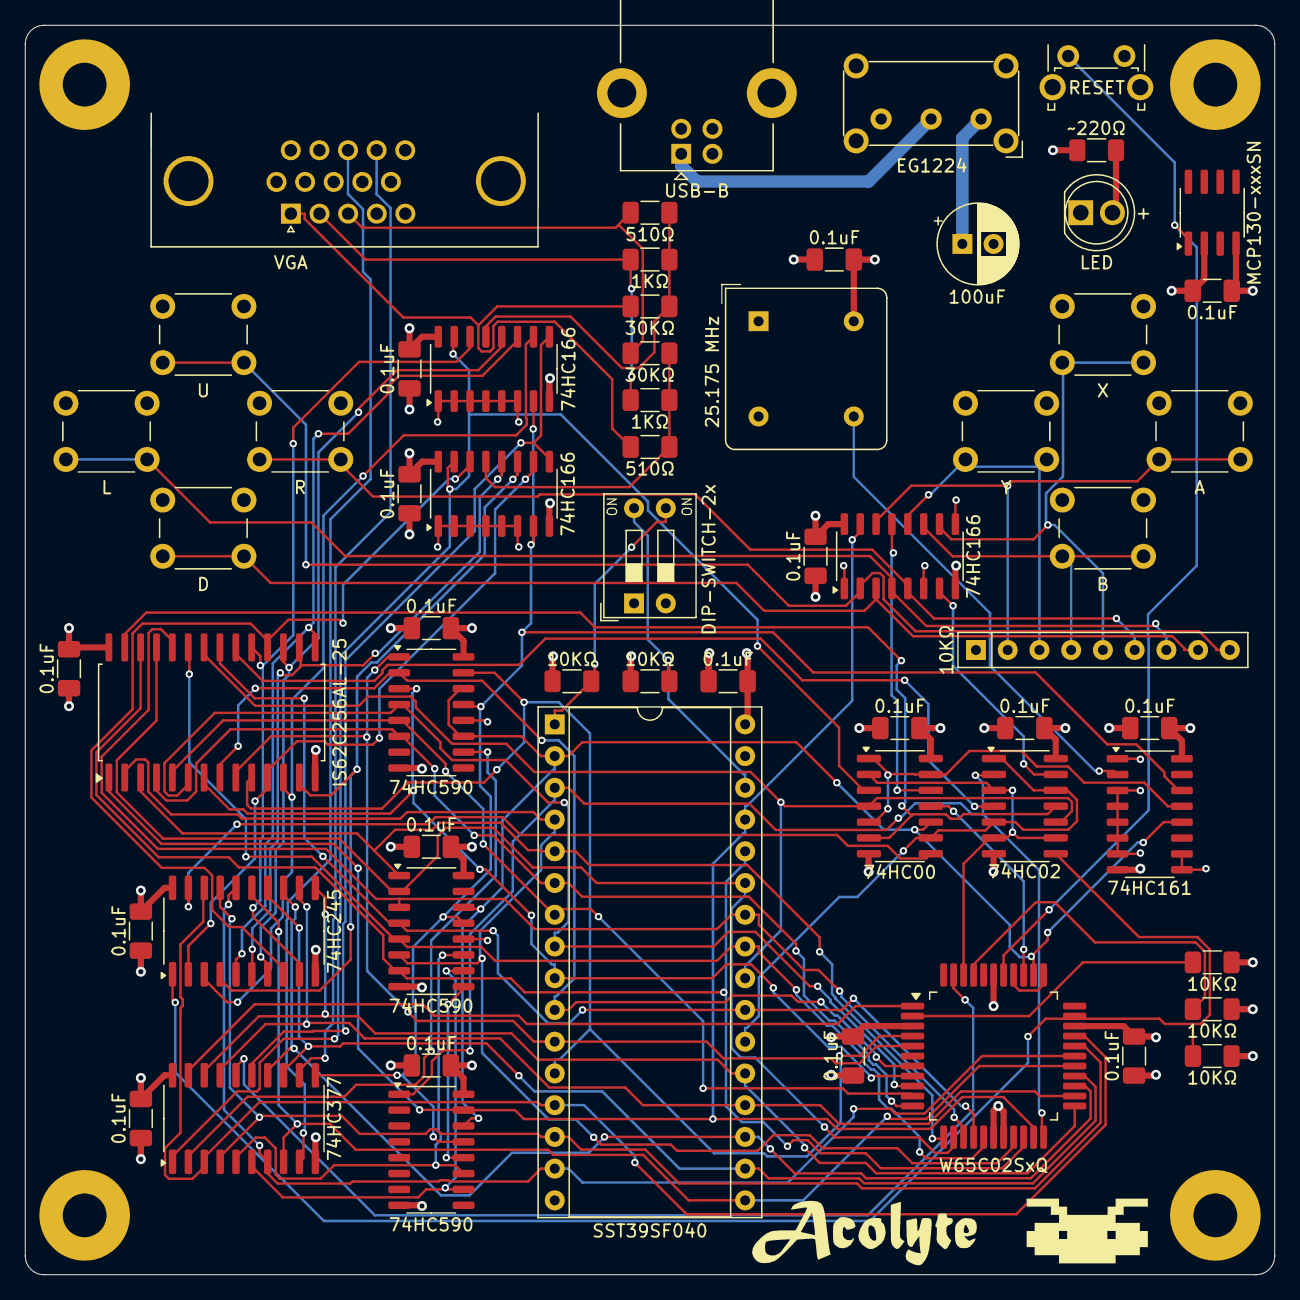
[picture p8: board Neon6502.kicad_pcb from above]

Board: 4 copper layers, 100.0 x 100.0 mm, 67 parts (0 on the bottom side), 79 nets.

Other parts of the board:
G100: LOGO; AlienImage
G101: LOGO; AcolyteImage

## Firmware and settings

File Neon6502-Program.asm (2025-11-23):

; Neon6502-Program.asm

; To compile
; ./dev65/bin/as65 Neon6502-Program.asm

; To parse
; ./Neon6502-Parser.o Neon6502-Program.lst Neon6502-Program.bin 32768 0 32768 0

; To combine
; ./Neon6502-Combiner.o Neon6502-SyncSignals.bin Neon6502-Program.bin Neon6502-Flash128KB.bin

; To burn
; minipro -p "SST39SF010" -w Neon6502-Flash128KB.bin

; To simulate
; ./Neon6502-Simulator.o Neon6502-Program.bin

	.65C02

video .EQU $0800

piece_type .EQU $00
piece_rot .EQU $01
piece_x .EQU $02
piece_y .EQU $03
prev_rot .EQU $04
prev_x .EQU $05
prev_y .EQU $06
block_color .EQU $07
block_x .EQU $08
block_y .EQU $09
frame_counter .EQU $0A
piece_descend .EQU $0B
piece_color .EQU $0C
piece_next .EQU $0D
piece_speed .EQU $0E
random_value .EQU $0F
lines_low .EQU $10
lines_high .EQU $11
buttons_value .EQU $12
buttons_wait .EQU $13
buttons_delay .EQU $14
digit_value .EQU $15
digit_x .EQU $16
digit_y .EQU $17
draw_flag .EQU $18
wait_rot .EQU $19
bag_pos .EQU $1A

bag_array .EQU $0020 ; uses 7 bytes

get_func .EQU $0030
get_low .EQU $0031
get_high .EQU $0032
get_rts .EQU $0033

put_func .EQU $0034
put_low .EQU $0035
put_high .EQU $0036
put_rts .EQU $0037

seq_func .EQU $0038
seq_low .EQU $0039
seq_high .EQU $003A
seq_rts .EQU $003B

rand_func .EQU $0040 ; current = 5 * previous + 17, uses 12 bytes

grid_page .EQU $0200


	.ORG $8000
reset
	SEI
	CLD

	JSR setup
	JSR clear

	LDA #$00
	STA lines_low
	LDA #$00
	STA lines_high

	JSR draw_bag
	LDA bag_array
	STA piece_next
	INC bag_pos
		
	LDA #$3C ; $3C = 1 second, $1E = 0.5 seconds, $0F = 0.25 seconds
	STA piece_speed

	LDA #$FF
	STA wait_rot

	LDA #$01
	STA draw_flag

	JMP loop_new

loop
	JSR draw_next
	JSR draw_score
	JSR buttons
	LDA buttons_value
	AND #$0A
	BNE reset
	JSR draw_moves
	LDA piece_descend
	BEQ loop_wait
	LDA #$02
	STA piece_descend
	LDA piece_rot
	CMP prev_rot
	BEQ loop_prev
	STA wait_rot
	LDA prev_rot
	STA piece_rot
loop_prev
	LDA prev_x
	STA piece_x
	LDA prev_y
	STA piece_y
	INC piece_y
	JMP loop_draw
loop_wait
	LDA wait_rot
	CMP #$FF
	BEQ loop_draw
	LDA piece_rot
	STA prev_rot
	LDA wait_rot
	STA piece_rot
	LDA #$FF
	STA wait_rot
loop_draw
	JSR draw_walls
	JSR draw_piece
	LDA #$00
	STA piece_descend
	LDA piece_color
	CMP #$55
	BEQ loop_grid
	CMP #$AA
	BEQ loop_new
loop_inf
	JSR buttons
	LDA buttons_value
	AND #$0A
	BEQ loop_jump
	JMP reset
loop_jump
	JMP loop_inf

loop_grid
	JSR draw_grid
	JMP loop

loop_new
	LDA piece_next
	STA piece_type
	LDX bag_pos
	LDA bag_array,X
	STA piece_next
	INC bag_pos
	LDA bag_pos
	CMP #$07
	BNE loop_create
	JSR draw_bag
loop_create
	LDA #$00
	STA piece_rot
	LDA #$00
	STA prev_rot
	LDA #$03
	STA piece_x
	LDA #$03
	STA prev_x
	LDA #$00
	STA piece_y
	LDA #$00
	STA prev_y
	LDA #$55
	STA piece_color
	LDA #$00
	STA piece_descend
	LDA #$00
	STA frame_counter
	JSR draw_grid
	JMP loop


setup
	LDA #$8D ; STAa
	STA put_func
	LDA #$00
	STA put_low
	LDA #$00
	STA put_high
	LDA #$60 ; RTS
	STA put_rts

	LDA #$AD ; LDAa
	STA get_func
	LDA #$00
	STA get_low
	LDA #$00
	STA get_high
	LDA #$60 ; RTS
	STA get_rts

	LDA #$BD ; LDAax
	STA seq_func
	LDA #$00
	STA seq_low
	LDA #$00
	STA seq_high
	LDA #$60 ; RTS
	STA seq_rts

	LDA #$A5 ; LDAz
	STA rand_func+0
	LDA #<random_value
	STA rand_func+1
	LDA #$0A ; ASL A
	STA rand_func+2
	LDA #$0A ; ASL A
	STA rand_func+3
	LDA #$18 ; CLC
	STA rand_func+4
	LDA #$65 ; ADCz
	STA rand_func+5
	LDA #<random_value
	STA rand_func+6
	LDA #$69 ; ADC#
	STA rand_func+7
	LDA #$11 ; 17
	STA rand_func+8
	LDA #$85 ; STAz
	STA rand_func+9
	LDA #<random_value
	STA rand_func+10
	LDA #$60 ; RTS
	STA rand_func+11

	RTS


clear
	LDA #<video
	STA put_low
	LDA #>video
	STA put_high
clear_sub_1
	LDA #$00
clear_sub_2
	JSR put_func
	INC put_low
	BNE clear_sub_2
	INC put_high
	LDA put_high
	CMP #$80
	BNE clear_sub_1
	LDX #$00
	LDA #$00
clear_sub_3
	STA grid_page,X
	INX
	BNE clear_sub_3
	RTS


buttons	
	LDA #$FF
	STA $8000
	LDX #$08
buttons_sub_1
	LSR A
	ORA #$80
	NOP
	NOP
	CLV
	NOP
	NOP
	NOP
	NOP
	BVC buttons_sub_2
	AND #$7F
buttons_sub_2
	STA $C000
	DEX
	BNE buttons_sub_1
	STA buttons_value
	RTS

	
draw_block
	TXA
	PHA
	TYA
	PHA

	LDX #$00
	LDA block_color
	BNE draw_block_sub_1
	LDA #<draw_block_data_0
	STA seq_low
	LDA #>draw_block_data_0
	STA seq_high
	JMP draw_block_sequence
draw_block_sub_1
	CMP #$55
	BNE draw_block_sub_2
	LDA #<draw_block_data_1
	STA seq_low
	LDA #>draw_block_data_1
	STA seq_high
	JMP draw_block_sequence
draw_block_sub_2
	CMP #$AA
	BNE draw_block_sub_3
	LDA #<draw_block_data_2
	STA seq_low
	LDA #>draw_block_data_2
	STA seq_high
	JMP draw_block_sequence
draw_block_sub_3
	CMP #$FF
	BNE draw_block_sub_4
	LDA #<draw_block_data_3
	STA seq_low
	LDA #>draw_block_data_3
	STA seq_high
	JMP draw_block_sequence
draw_block_sub_4
	PLA
	TAY
	PLA
	TAX
	RTS

draw_block_sequence
	LDA block_y
	ASL A
	ASL A
	CLC
	ADC #>video
	CLC
	ADC #$10 ; vertical shift
	STA put_high
	LDA block_x
	ASL A
	CLC
	ADC #<video
	CLC
	ADC #$14 ; horizontal shift
	STA put_low
	JSR seq_func
	INX
	JSR put_func
	INC put_low
	JSR seq_func
	INX
	JSR put_func
	LDA put_low
	CLC
	ADC #$7F
	STA put_low
	JSR seq_func
	INX
	JSR put_func
	INC put_low
	JSR seq_func
	INX
	JSR put_func

	INC put_high

	LDA put_low
	CLC
	ADC #$7F
	STA put_low
	JSR seq_func
	INX
	JSR put_func
	INC put_low
	JSR seq_func
	INX
	JSR put_func
	LDA put_low
	CLC
	ADC #$7F
	STA put_low
	JSR seq_func
	INX
	JSR put_func
	INC put_low
	JSR seq_func
	INX
	JSR put_func
	
	INC put_high

	LDA put_low
	CLC
	ADC #$7F
	STA put_low
	JSR seq_func
	INX
	JSR put_func
	INC put_low
	JSR seq_func
	INX
	JSR put_func
	LDA put_low
	CLC
	ADC #$7F
	STA put_low
	JSR seq_func
	INX
	JSR put_func
	INC put_low
	JSR seq_func
	INX
	JSR put_func
	
	INC put_high

	LDA put_low
	CLC
	ADC #$7F
	STA put_low
	JSR seq_func
	INX
	JSR put_func
	INC put_low
	JSR seq_func
	INX
	JSR put_func
	LDA put_low
	CLC
	ADC #$7F
	STA put_low
	JSR seq_func
	INX
	JSR put_func
	INC put_low
	JSR seq_func
	INX
	JSR put_func

	PLA
	TAY
	PLA
	TAX
	RTS
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
